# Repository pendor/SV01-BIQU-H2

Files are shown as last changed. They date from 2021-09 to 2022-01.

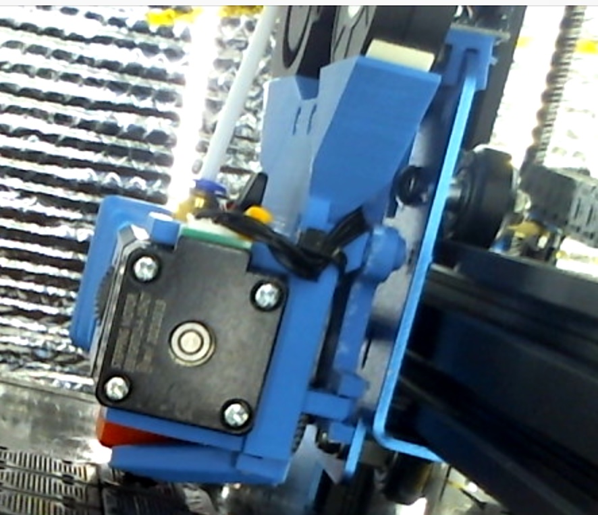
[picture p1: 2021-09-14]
images/installed.jpg

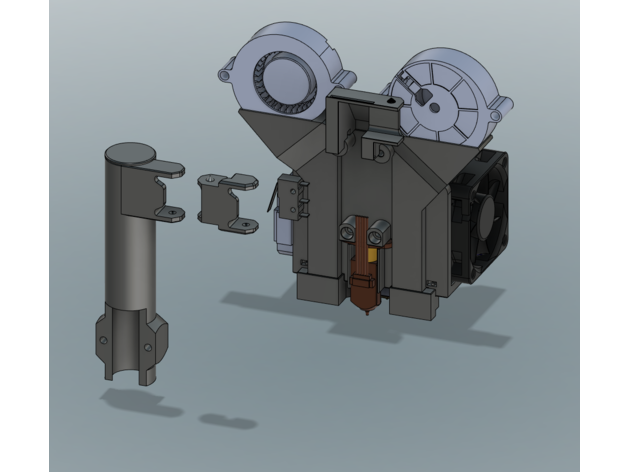
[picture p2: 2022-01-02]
originals/Ender 6 - BIQU H2 Extruder/images/back_overview.png

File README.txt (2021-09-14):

Adapter plates to install BIQU H2 extruder on a Sovol SV-01 with rear-mounted dual cooling fans & BLTouch mount.

By Zachary Bedell <pendorbound@gmail.com>.  licensed under the Creative Commons - Attribution license [https://creativecommons.org/licenses/by/4.0/].

Based on:
"Ender 6 - BIQU H2 Extruder" by windischb on Thingiverse: https://www.thingiverse.com/thing:4762042
"SOVOL SV01 BIQU-H2 Adapter" by thro42 on Thingiverse: https://www.thingiverse.com/thing:4890363

Also included for design reference (but not part of the final model) are:
"Biqu H2 Direct drive extruder Model" by 3D_LC on Thingiverse: https://www.thingiverse.com/thing:4740224
"Sovol SV01 Complete X  Carriage Step Files" by MadHatter3D on Thingiverse: https://www.thingiverse.com/thing:4070979

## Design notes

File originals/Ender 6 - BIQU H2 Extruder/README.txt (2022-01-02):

Ender 6 - BIQU H2 Extruder by windischb on Thingiverse: https://www.thingiverse.com/thing:4762042

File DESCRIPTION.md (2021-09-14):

This thing allows mounting a BIQU-H2 extruder to a Sovol SV-01 original gantry plate with dual rear-mounted part cooling fans and an integrated BLTouch mount.  I created this because I found when I installed the excellent [Hero Yourself kit by FullmoonCat](https://www.thingiverse.com/thing:4870742), my PLA curling issues were fixed as if by magic.  The extra cooling of two well-targeted 5015 fans fixed my print.  Switching to an H2 extruder, I wasn't able to find a dual-fan solution which fit the SV-01.  

I initially found [thro42's adapter for the H2 on an SV-01](https://www.thingiverse.com/thing:4890363), and that worked pretty well.  Losing the extra cooling however put me back in PLA curling territory.  The fan duct blocked a lot of visibility and access for calibration.  The BLTouch felt like a sitting duck way out in front.

Then I found [windischb's H2 mount for the Ender 6](https://www.thingiverse.com/thing:4762042), and I started to salivate.  Dual fans, mounted up high and ducted down so they don't block visibility, integrated (and I'd dare to call it "armored") BLTouch mounting that was super close to the extruder point and fully protected by plastic on all sides.  Only problem is I don't have an Ender 6.  What's to do but fire up OpenSCAD and proceed to make a mockery of thro42 & windischb'2 elegant designs...

I used OpenSCAD to nip & tuck the original STL's rather than try to get them both functional in FreeCAD or sell my soul to Autodesk.  I'm not proud of the process, but the result works...  Also used were a [dummy model of the BIQU H2 by 3D_LC](https://www.thingiverse.com/thing:4740224) and the [SV-01 gantry plate by MadHatter3D](https://www.thingiverse.com/thing:4070979).  Those aren't included in the final rendered model, only used for alignment during design.

This upload contains only the final STL files for this design.  The full "source" including STL's from the several remixed things and OpenSCAD source are available in [Github](https://github.com/pendor/SV01-BIQU-H2).  I didn't include all of that here since Thingiverse's upload format seems to limit what can be included.  

The rendered pieces include:

* sovol-biquh2-adapter.stl - A modified version of thro42's mounting plate
* sovol-biquh2-shroud.stl - The fan ducting which attaches between the adapter and the H2
* sovol-biquh2-nozzle-{left|right}.stl - Left & right ducts which are attached with screws to the main shroud.  Printed separately because the thing already needs more than enough supports to print...

So why the two-layer adapter plate?  I'm lazy & it worked.  The duct locations in windischb's Ender mount don't line up well with the original mounting screws on the SV-01 gantry.  Using that mount directly would require either re-working the duct locations or driving screws right through the air ducts.  The two-piece approach also allows mounting the H2 and zip-tying all the wiring down nice and neat with the shroud as a separate part you can work on more easily.  Once everything is in place and bundled up tight, four screws, and you're done.  No trying to tuck wiring into the right place as you're contorting yourself around the printer and carefully tightening screws to not pinch anything.

The main changes I made to windischb's mount are:

* Added some zip tie points to cinch down wiring.
* Thickened some parts for reinforcement.  My first print started separating along the thinnest part.
* Moved the screws around to meet up with exposed spots on the adapter plate.
* Added sloping ramps up to some of the protrusions on the back so as to print with fewer supports.
* Designed new fan nozzles that get closer to the part and put more air where it needs to be.  I don't have the skill to do any kind of flow analysis on these, so I'm just guessing / making it up.  The nozzle mounting didn't change, so you can print and use windischb's originals if you like them better.
    
The changes to thro42's adapter plate were much simpler.  I added additional screw holes (and filled some I didn't need) to enable inserting threaded inserts to match the shroud.  I also added some forked alignment tabs to the bottom edge of both pieces to keep things a little tighter even with all the screw points relatively high up on the model.

All told, this works pretty well.  It went together easily, cools my parts, and I'm really happy with it.

To Do:
------

I'd like to try integrating the cable guide and fan mounting from [Cable Guide for Ender 6 - BIQU H2 Extruder](https://www.thingiverse.com/thing:4907102).  That original thing doesn't fit with the adapter plate or original SV-01 gantry.  Adding at least screw holes for the 5015 fans would be nice, though double-sided tape seems to be working alright so far.  The OpenSCAD file contains a start to that adaptation, but I haven't tried it yet.

Add a groove for the tabs that protrude from the 5015 fans.

Check alignment on bottom BIQU screw.  Not sure if my print warped or if it's a little bit off.

Hardware:
---------

* (4x) M4x12 screws (adapter plate to gantry - original M4's on the SV01 extruder probably aren't long enough)
* (4x) M3 heat set threaded inserts
* (4x) M3x20 screws (shroud to adapter plate)
* (3x) M3x8 screws (H2 to shroud - two are usually included with the BIQU kit)
* (2x) M2x12 screws (fan nozzles to shroud)
* (2x) M2 nuts (same)
* (5x) ZIP ties (1mm wide)
* (2x) 5015 blower fans
* Double-sided sticky foam tape (to mount fans)

Assembly:
---------

1. Insert the threaded heat sets into the back adapter plate at the points that match up with the screws on the fan shroud.  You could optionally leave out the right-most insert and use a longer M3 screw in that hole that would go all the way to the threaded insert on the original SV-01 plate, going through both the shroud and adapter plate.

2. Insert an M2 nut into each of the catches near the bottom of the shroud, line up the two fan nozzles, and screw them in place with M2 screws.  Be a little bit careful.  They're fragile.  Depending on how it printed, you may need to trim out some extra material in the nozzle slots to get them to seat well.

3. Screw the adapter plate onto the SV-01 gantry using the 4 M4 holes that line up with the original extruder stepper mounting holes.  You'll probably need to tighten the screws incrementally or risk flexing the plate too much.

4. Insert the BLTouch in the back of the shroud with the plug facing away from the extruder.  

5. Insert the two 5015 fans at the top of the shroud.  They kind of "pop" in if you line them up then twist them into place.  I found putting tape on the inside of the ducts near the top on the outer side allowed lining up the fans, rotating them to pop, and in the process they hit the tape and stick in place.  Note you may need to splice the fans together or create a splitter for their power wires.

6. Attach the BIQU-H2 to the front of the shroud with three M3 screws (two top, one bottom).  Route the heater and thermistor wires around the back and zip tie them using the provided tiedown points.  The wires should fit (mostly) into the grooves to either side of the BLTouch.

7. Wire the extruder stepper and extruder cooling fan, and route the wires around the back of the shroud, zip tying on each side to provided tie-downs.

8. Route the wires for heater, thermistor, BLTouch, extruder fan, extruder stepper, and 5015 fans to the back-center of the shroud and zip tie them all together to the top of the shroud using the provided tie-down between the top two mounting screws.

9. Make sure all wires are clear of screw hold and support pedestals.  They should be if they take straight lines between the zip tie points.  You may need to be careful about how zip ties are oriented so their "head" doesn't protrude past where the shroud and adapter plate meet.

10. Line up the shroud with the adapter plate already on the gantry, and screw into place with 4 M3 screws.

11. Double check no wiring is pinched, hanging down towards the build plate, etc.  There's a hole in the original SV-01 plate near where the wires come up from the shroud.  I wrapped my wires in some wire loom to protect them, then zip tied them there.  I have a drag chain for the gantry wires that lined up and worked well from that point.  

12. Route your hotend wires back to your control module as you like.  I've got connector plugs in mine near the gantry which is easy and also looks like hot garbage...

Print Settings:
---------------

See Cura screenshots for best orientation.  You'll need to rotate the adapter plate and cooling ducts.

You'll probably need some support blockers on the bottom of the shroud to prevent the duct mounting & screws from getting filled up.  Also on the top of the shroud to prevent generated supports that aren't needed with the sloping build up to the screw pedestals.  Tree supports touching build plate only in Cura worked well for me.

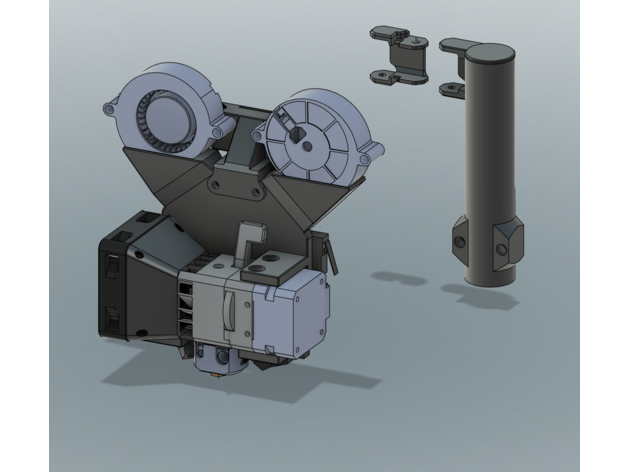
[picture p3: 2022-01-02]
originals/Ender 6 - BIQU H2 Extruder/images/overview.png

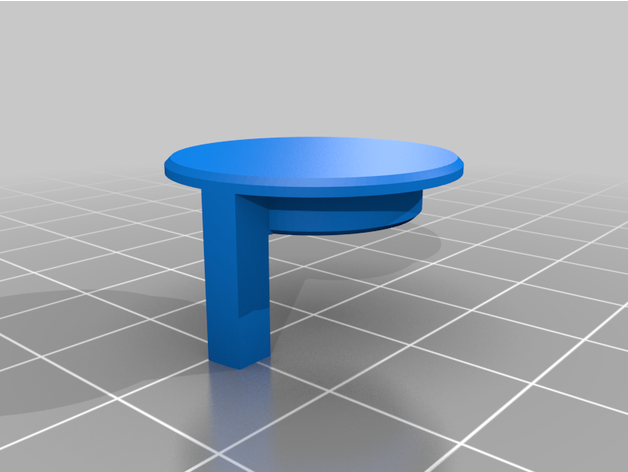
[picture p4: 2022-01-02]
originals/Ender 6 - BIQU H2 Extruder/images/CableChainDock_RearCover.png

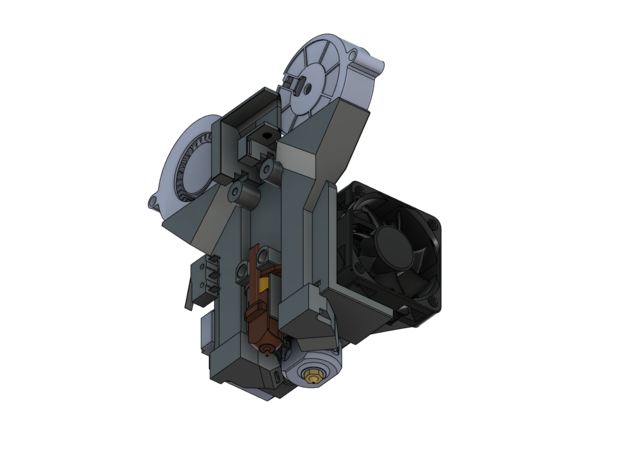
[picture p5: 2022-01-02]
originals/Ender 6 - BIQU H2 Extruder/images/bottom.png

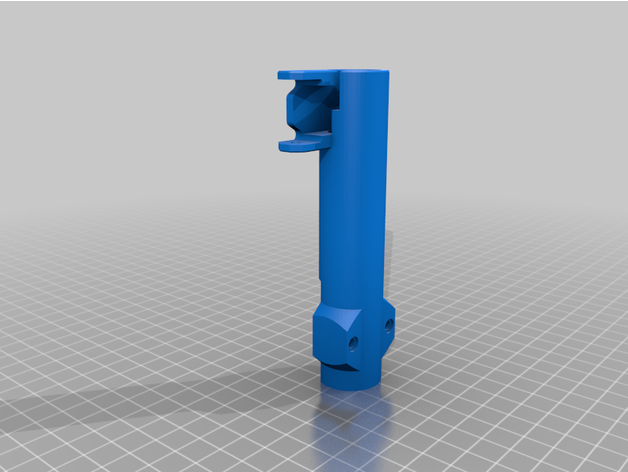
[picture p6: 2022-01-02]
originals/Ender 6 - BIQU H2 Extruder/images/CableChainDock_Rear.png

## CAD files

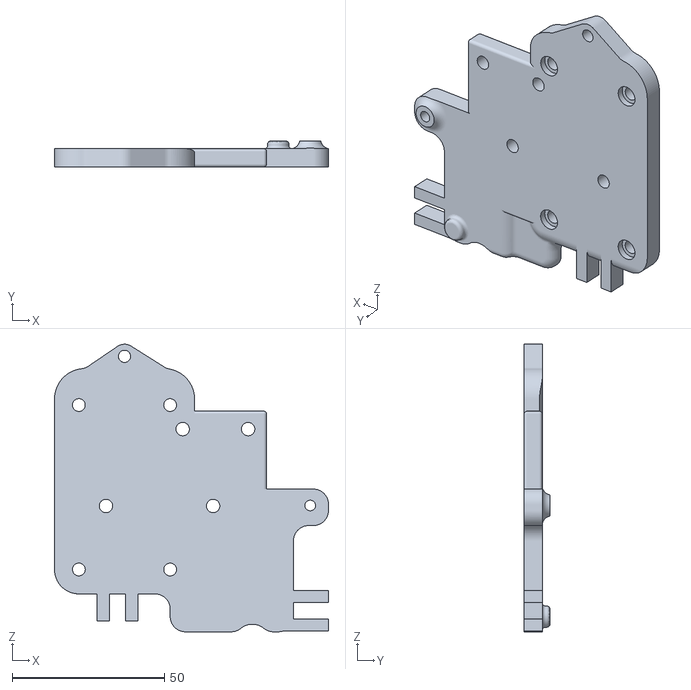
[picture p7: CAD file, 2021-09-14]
files/sovol-biquh2-adapter.stl
90.0 x 8.50 x 94.5

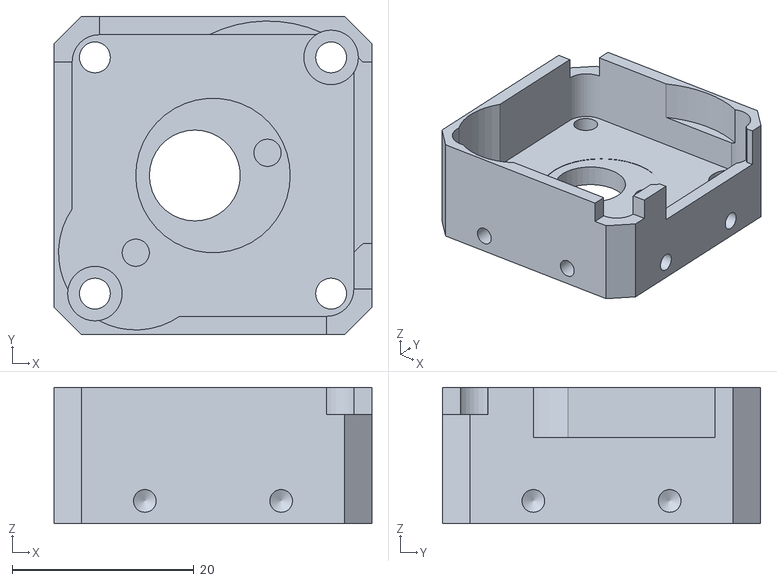
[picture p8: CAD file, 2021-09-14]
imports/h2model/Biqu_H2_-_Biqu_H2_Interface_Moteur-1.STL
35.0 x 35.0 x 15.0

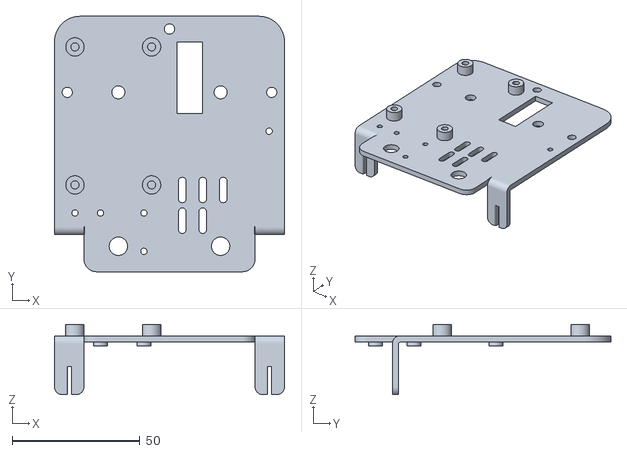
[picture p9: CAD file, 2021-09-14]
imports/Sovol_SV01_Carriage_Bracket.stl
90.0 x 100.0 x 27.5

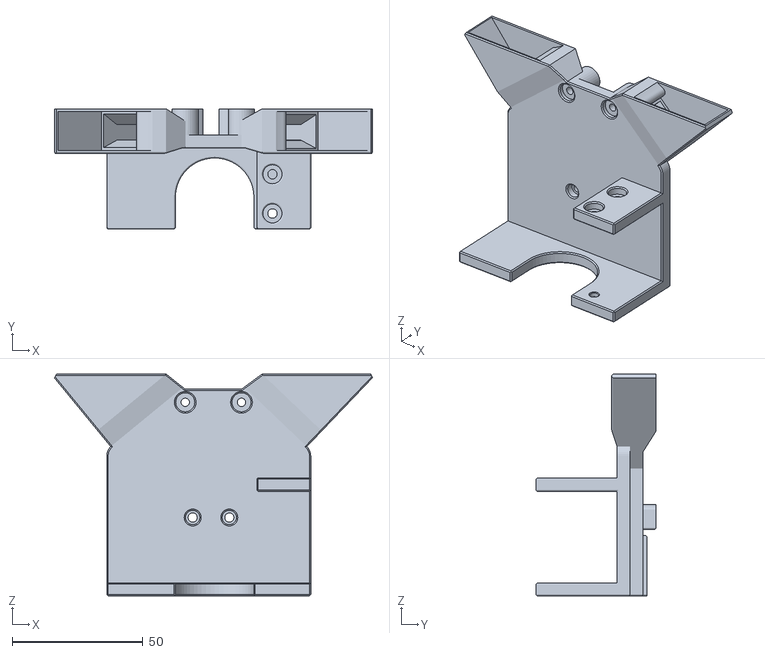
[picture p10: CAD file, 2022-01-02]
originals/Ender 6 - BIQU H2 Extruder/files/BIQU_H2_Halterung.stl
121.6 x 46.0 x 84.9

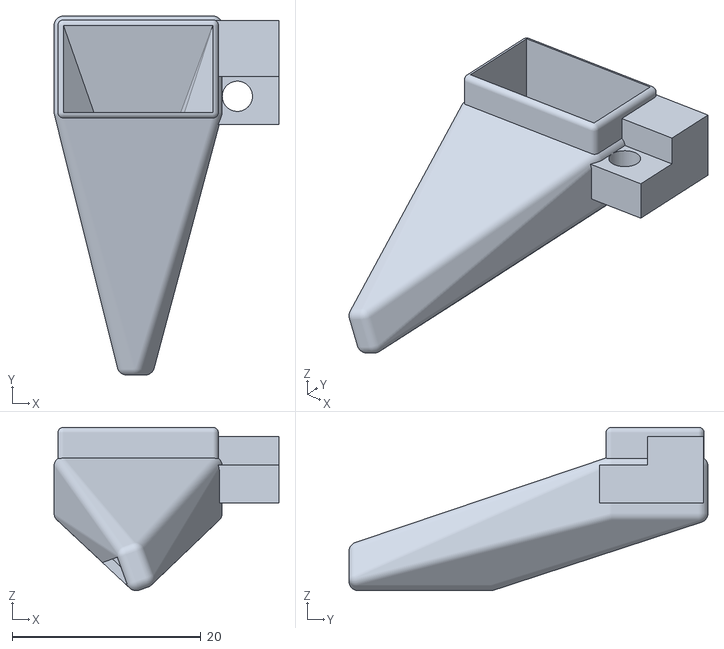
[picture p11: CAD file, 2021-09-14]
files/sovol-biquh2-nozzle-right.stl
23.8 x 38.0 x 17.3

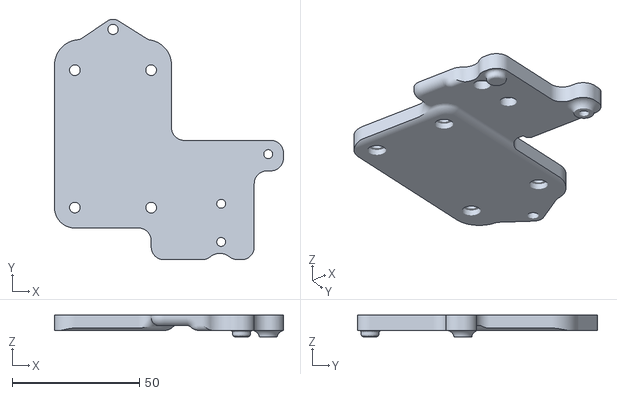
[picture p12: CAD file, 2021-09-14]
imports/BIQU-AdapterPlatte.stl
90.0 x 94.5 x 8.50

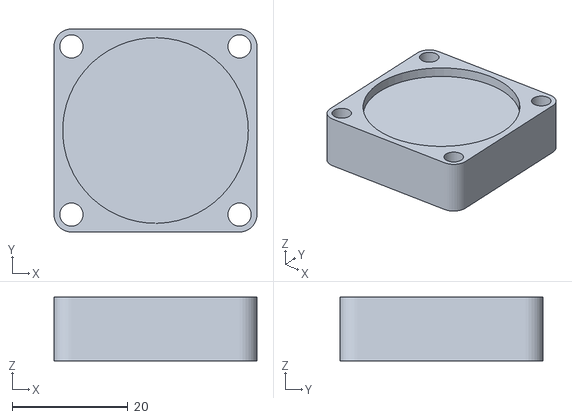
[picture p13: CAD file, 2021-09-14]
imports/h2model/Biqu_H2_-_3511_Fan-1.STL
35.0 x 35.0 x 11.0

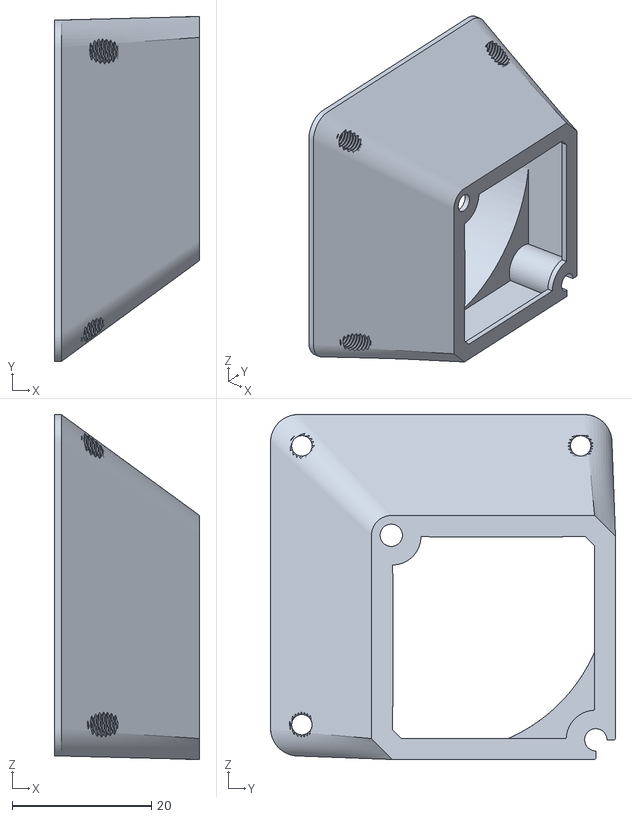
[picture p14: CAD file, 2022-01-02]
originals/Ender 6 - BIQU H2 Extruder/files/HotendLüfterAdapter_-_50x50.stl
20.8 x 49.5 x 49.5

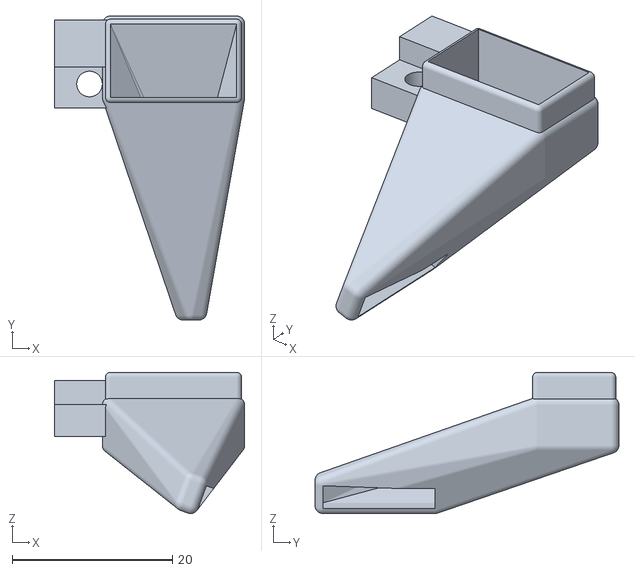
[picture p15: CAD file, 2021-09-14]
files/sovol-biquh2-nozzle-left.stl
23.8 x 38.0 x 17.6

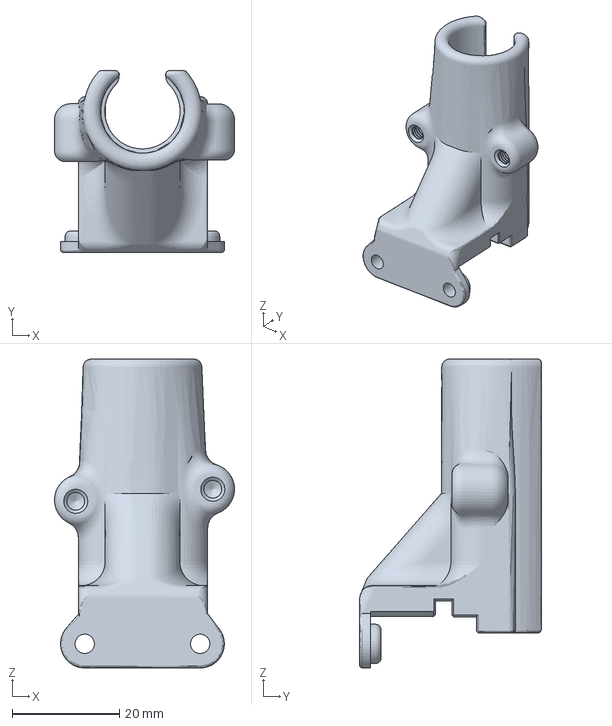
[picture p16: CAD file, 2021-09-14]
imports/BIQU_H2_Kabelhalter_für_B.W._sein_Halter_reducedfaces_repaired.3mf
33.5 x 33.8 x 57.5 mm

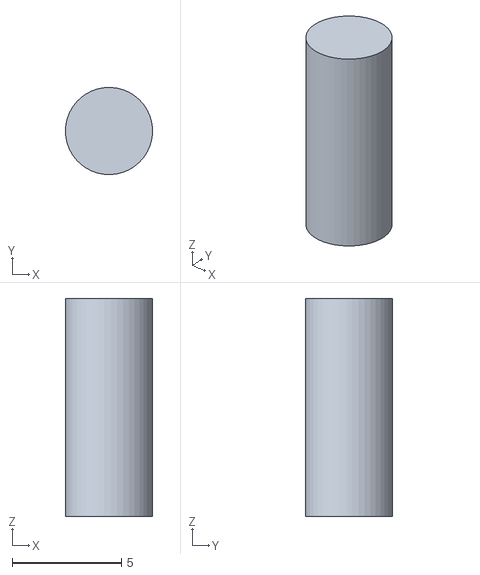
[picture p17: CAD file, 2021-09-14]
imports/h2model/Biqu_H2_-_Axe_Bras-1.STL
4.00 x 4.00 x 10.0

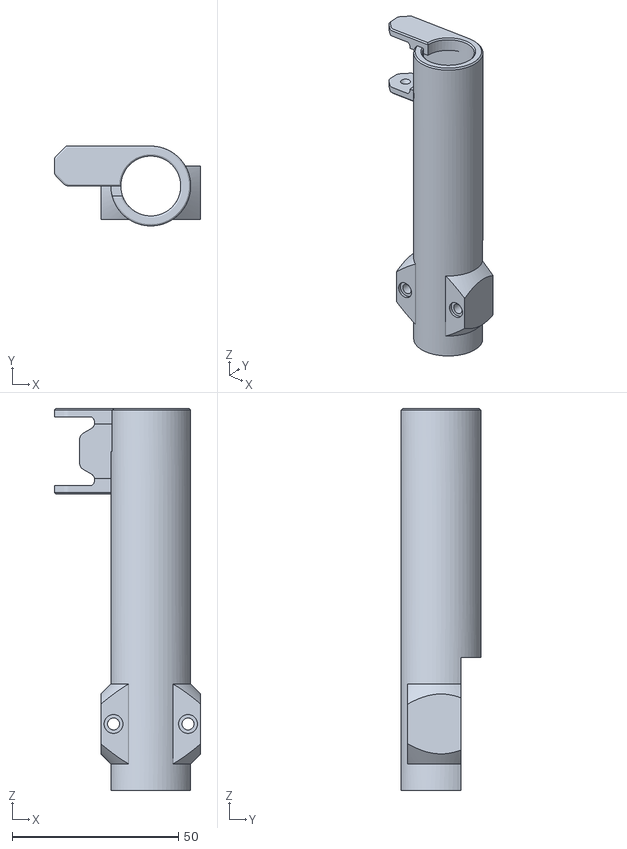
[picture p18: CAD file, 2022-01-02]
originals/Ender 6 - BIQU H2 Extruder/files/CableChainDock_Rear.stl
44.0 x 24.0 x 114.8

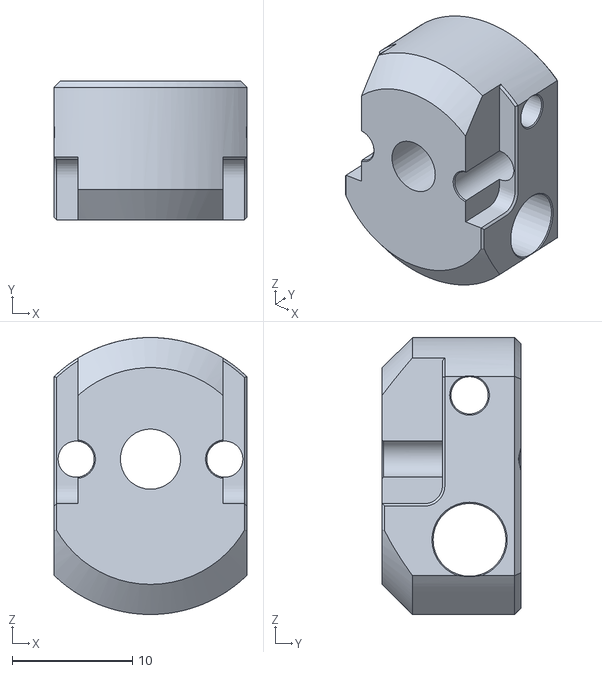
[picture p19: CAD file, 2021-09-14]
imports/h2model/Biqu_H2_-_Phaetus_HB-1.STL
16.0 x 11.5 x 23.0

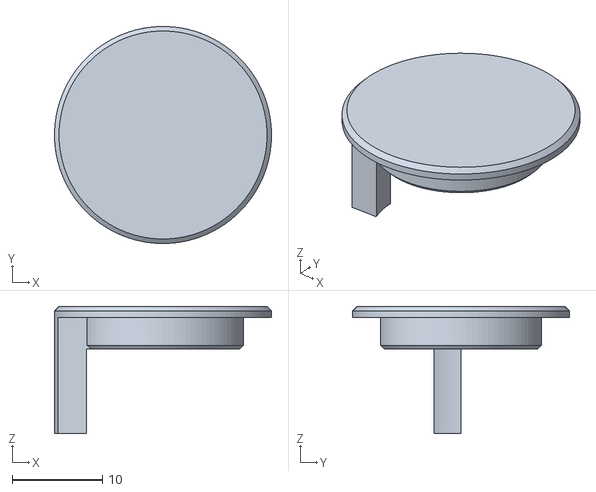
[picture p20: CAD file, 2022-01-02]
originals/Ender 6 - BIQU H2 Extruder/files/CableChainDock_RearCover.stl
24.0 x 24.0 x 14.1

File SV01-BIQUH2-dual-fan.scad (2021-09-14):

// Higher definition curves
//$fs = 0.01;


build=false;
part="all";

if(!build) {
  $fn=16;
  
  // Show the original SV-01 gantry plate
  //translate([-50, 0, -60]) rotate([90,0,0]) import("imports/Sovol_SV01_Carriage_Bracket.stl");

  // Show the BIQU-H2 extruder
  translate([10,-14.5,0]) extruder();

  adapter();
  shroud();
  nozzles("both");
//  wireguide();
  
} else {
  $fn=64;
  if(part == "adapter") {
    adapter();
  } else if(part == "shroud") {
    shroud();
  } else if(part == "nozzle-left") {
    nozzles("left");
  } else if(part == "nozzle-right") {
    nozzles("right");
  } else if(part == "wireguide") {
    wireguide();
  } else {
    echo("Unknown part:");
    echo(part);
  }
}

nozzle_z_min = -1.4;
nozzle_height = 3;
nozzle_width = 14;
duct_fitting_height = 3.5;

lduct_size = [15.8, 9.2, 5];
lduct_pos = [42.9, -45.2, 5.8];

lnoz_size = [1, nozzle_width, nozzle_height];
lnoz_pos = [52, -72, nozzle_z_min];

lnoz_rot = [0,20,0];


rduct_size = lduct_size;
rduct_pos = [85.3, -45.2, 5.8];

rnoz_size = lnoz_size;
rnoz_pos = [93, -72, nozzle_z_min];

rnoz_rot = [0,-20,0];

mounting_size = [7,11,4];

module nozzles(side) {
  if(side == "right" || side == "both") {
    minkduct(duct_fitting_height, rduct_size, rduct_pos, rnoz_size, rnoz_pos, rnoz_rot, 1);
  }


  if(side == "left" || side == "both") {
    minkduct(duct_fitting_height, lduct_size, lduct_pos, lnoz_size, lnoz_pos, lnoz_rot, 0);
  }
}

module wireguide() {
  translate([33, -46.8, 83.2]) {
    
    difference() {
    import("imports/BIQU_H2_Kabelhalter_für_B.W._sein_Halter_reducedfaces_repaired.3mf");
    translate([27,15,-8]) cube([26, 12, 30]);
    }
    // This might be a problem for an XT-60 connector...    
    //translate([32,30.5,4.5]) cube([16, 2, 50]);
  }
}

module minkduct(dheight, in_size, in_pos, out_size, out_pos, noz_rot, noz_on_left) {
  
  difference() {
    union() {
      minkowski() {
        translate([0,0,dheight])
        translate(in_pos)
        cube(in_size);
        sphere(.6);
      }
      
       // Alignment on the screw tab
       translate([(noz_on_left ? in_size[0]  : - mounting_size[0]), 
      3.8, 1.1])
      translate(in_pos)
      cube([7,5.9,7]);
      
      // Tab for mounting screw
      difference() {
        translate([
          (noz_on_left ? in_size[0]  : - mounting_size[0]), 
          -1.3, 
          1.1]
        )
        translate(in_pos)
        cube(mounting_size);
      translate([(noz_on_left ? in_size[0] + 2.6 : -2.6), in_size[1] - 7.5, 4])
        translate(in_pos)
        cylinder(r=3/2+.1, h=mounting_size[2]+3, center=true);
        
      }
    
      difference() {
        minkowski() {
          hullduct(in_size, in_pos, out_size, out_pos, noz_rot);
          sphere(1);
        }
        hullduct(in_size, in_pos, out_size, out_pos, noz_rot);
        
        translate(noz_on_left ? [-3,0,-1] : [0,0,0])
        translate(out_pos) 
        rotate(noz_rot)
        cube([3, nozzle_width, nozzle_height]);
        
      }
    }
    
    scale([1,1,1.5])
    translate([0,0,dheight-4.2])
    translate(in_pos)
    cube(in_size);
  }
}



module hullduct(in_size, in_pos, out_size, out_pos, noz_rot) {
  hull() {
    translate(in_pos)
    cube(in_size);
  
    translate(out_pos)
    rotate(noz_rot)
    cube(out_size);
  }
}


module adapter() {
  union() {  
    difference() {  
      //  color("blue")  
      union() {
        translate([-50, 0, -60])
        rotate([90,0,0])
        import("imports/BIQU-AdapterPlatte.stl");

        translate([61.7,-31.5,35])
        roundedcube(size=[28,6,56], radius=1);
        
        // Fill in existing H2 mounts
        translate([81,-31.5,22])
        cube([8,6,8]);
        
        // Alignment forks for the Ender plate
        translate([34, -31.5, 22]) cube([4,6,12]);
        translate([43.4, -31.5, 22]) cube([4,6,12]);
        translate([98, -31.5, 28.1]) cube([12,6,4]);
        translate([92, -31.5, 18.8]) cube([18,6,4]);
      } 

      translate([83.6, -16.5, 85.1]) threadedInsert(3);
      translate([62.1, -16.5, 85.1]) threadedInsert(3);
      
      translate([36.9, -15.3, 59.85])threadedInsert(3);
      translate([72.1, -15.3, 59.85]) threadedInsert(3);
    }
  }
}


// Move it into position then right by 10 to miss SV01 adapter's mounts
module shroud() {
  translate([10,-14.5,0]) 
  union() {
  difference() {
    //color("red")
      translate([23,-32,3.2])
    difference() {
      union() {
        import("imports/BIQU_H2_Halterung_repaired.3mf");
        
        // Pedestals for higher screws
        translate([-.5, 5, 52.8]) cube([8,10,7.5]);
        translate([67, 5, 52.8]) cube([8,10,7.5]);
                
        // Ramps up to pedestals
        translate([-.5, 15, 52.8]) rotate([180,0,0]) prism(8, 5.4, 4);
        translate([67, 15, 52.8]) rotate([180,0,0]) prism(8, 5.4, 4);

        // Zip tie points (back)
        translate([2.5, 13, 60]) rotate([0,0,90]) tiedown();

        translate([32, 9.4, 45.6]) tiedown();  
        translate([46, 9.4, 45.6]) tiedown();

        translate([39, 6.8, 80.4]) tiedown();

        translate([76.9, 8, 50.5]) rotate([0,0,90]) tiedown();

        // Zip tie points (front)
//        translate([39, -1.7, 70]) rotate([0,90,0]) tiedown();
        
        // Fill in existing lower mounting holes
        translate([28, 0, 34.35]) cube([8,15,9]);
        translate([42, 0, 34.35]) cube([8,15,9]);
        
        // Tounges to go into the alignment forks 
        // (Note .2 smaller than matching slot)
        translate([5.3,4.9,19.7]) cube([4.8, 16, 8]);
        translate([68,4.9,19.65]) cube([8, 16, 4.8]);
        
        
        // Extra bracketing on both edges
        translate([-2.9, 1, 7.85]) cube([5, 7, 40]);        
        translate([75.4, 2, 7.85]) cube([4.5, 8, 40]);
        
        
        // Add thickness to back middle wall
        translate([25, 5, 34]) cube([28, 2, 44]);
        
        
        // Add thickness & support ramp to fan side wall
        translate([-2.9,5,19.5]) cube([13.5, 4.9, 37]);
        translate([-2.9, 9.9, 19.5]) rotate([180,0,0]) prism(13.1, 5, 4.23);
        
        // Add thickness to extruder side wall
        translate([66.7, 5, 19.65]) cube([9, 4.9, 28]);        
        translate([66.7, 5, 47]) cube([8.2, 4.9, 2]);
        translate([67.7, 9.9, 19.5]) rotate([180,0,0]) prism(10, 5, 4.23);
        
        
  
        // Ramps up to top screw holes for less support
        translate([24, 5, 76.5]) cube([10, 10, 3.5]);
        translate([24, 15, 76.5]) rotate([180,0,0]) prism(10, 8, 4);
  
        translate([45.5, 5, 76.5]) cube([10, 10, 3.5]);
        translate([45.5, 15, 76.5]) rotate([180,0,0]) prism(10, 8, 4);
  
  
        
        // Original ducts for height reference
        //import("imports/Luft_Düse_Rechts.stl");
        //import("imports/Luft_Düse_Links.stl");

        
        // Screws break preview, but work in full
        // render.  So show as green stubs in preview
        // but difference them out properly for render.
        if(!build) {
          translate([4, 27.9, 56.8]) screw(3);
          translate([71, 27.9, 56.8]) screw(3);
        } 
      }
      // New higher screw holes      
      if(build) {
        translate([4, 27.9, 56.8]) screw(3);
        translate([71, 27.9, 56.8]) screw(3);
      }
    }
  }
}

}

module tiedown() {
  rotate([0,90,0])
  difference() {
    roundedcube([7,6,4], center=true);
    roundedcube([5,4,4.2], center=true);
  }
}

module extruder() {
  color("green")
  translate([110.3,-32,53.3])
  rotate([0,-90,0])
  rotate([0,0,-90])
  translate([0,-60,0])
  union() {
    import("imports/h2model/Biqu_H2_-_Biqu_H2_Motor-1.STL");
    import("imports/h2model/Biqu_H2_-_Biqu_H2_Interface_Moteur-1.STL");
    import("imports/h2model/Biqu_H2_-_Biqu_H2_Heatsink-1.STL");
    import("imports/h2model/Biqu_H2_-_Phaetus_HB-1.STL");
    import("imports/h2model/Biqu_H2_-_HeatBreak-1.STL");
    import("imports/h2model/Biqu_H2_-_Silicone_Sock-1.STL");    
    import("imports/h2model/Biqu_H2_-_3511_Fan-1.STL");
    import("imports/h2model/Biqu_H2_-_Biqu_H2_Bras-1.STL");
    import("imports/h2model/Biqu_H2_-_E3D_V6_Nozzle_0.4mm-1.STL");

    // Plane for the bed for testing:
    // rotate([90,0,0]) cube([100,100,1]);
  }
}

// Hole for inserting a threaded insert
module threadedInsert(screw_dia) {
  color("green")
  rotate([90,0,0])  
  cylinder(h=28, r=((screw_dia + 1)/2) + .2);
}

// Screw with a countersunk hole
module screw(screw_dia) {
  color("green")
  rotate([90,0,0])  
  union() {
    cylinder(h=28, r=(screw_dia + .2)/2);
    translate([0,0,26]) 
    cylinder(h=2, r=(screw_dia + .6));
  }
}

module roundedcube(size = [1, 1, 1], center = false, radius = 0.5, apply_to = "all") {
	// If single value, convert to [x, y, z] vector
	size = (size[0] == undef) ? [size, size, size] : size;

	translate_min = radius;
	translate_xmax = size[0] - radius;
	translate_ymax = size[1] - radius;
	translate_zmax = size[2] - radius;
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

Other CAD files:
imports/BIQU_H2_Halterung_repaired.3mf
imports/h2model/Biqu_H2.STEP
originals/Ender 6 - BIQU H2 Extruder/files/HotendLüfterAdapter_-_40x40.stl
imports/h2model/Biqu_H2_-_Biqu_H2_Bras-1.STL
imports/h2model/Biqu_H2_-_Arm_Gear-1.STL
imports/h2model/Biqu_H2_-_Biqu_H2_Heatsink-1.STL
imports/h2model/Biqu_H2_-_Biqu_H2_Motor-1.STL
imports/h2model/Biqu_H2_-_E3D_V6_Nozzle_0.4mm-1.STL
imports/h2model/Biqu_H2_-_Gear_1-1.STL
imports/h2model/Biqu_H2_-_Gear_2-1.STL
imports/h2model/Biqu_H2_-_HeatBreak-1.STL
imports/h2model/Biqu_H2_-_Silicone_Sock-1.STL
originals/Ender 6 - BIQU H2 Extruder/files/BIQU_H2.f3d
originals/Ender 6 - BIQU H2 Extruder/files/CableChainDock.stl
originals/Ender 6 - BIQU H2 Extruder/files/Luft_Düse_Links.stl
originals/Ender 6 - BIQU H2 Extruder/files/Luft_Düse_Rechts.stl

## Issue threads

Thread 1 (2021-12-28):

Nice Job.

ids444, 2021-12-28:
Looks like the original (https://www.thingiverse.com/thing:4762042) is 404 now.

I'm trying to mount the H2 on an Anycubic Chiron and like you I didn't like any I found.

Going to yry and adapt yours to the Chiron. Wish me luck.

pendor, 2022-01-02:
Thank you!  Good luck with the remix.

It's unfortunate the original is missing.  Considering it's licensed under CC, I don't see any problem mirroring from my original download here. I dunno if the Fusion 360 source will help you any, but it's there just in case.

Closed 2022-01-02.

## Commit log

2021-09-14 Initial import
    [BIQU-AdapterPlatte.stl, BIQU_H2_Halterung_repaired.3mf, BIQU_H2_Kabelhalter_für_B.W._sein_Halter_reducedfaces_repaired.3mf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]
2022-01-02 #1 - Add missing original ender 6 source files
    [BIQU_H2.f3d, BIQU_H2_Halterung.stl, CableChainDock.stl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]
